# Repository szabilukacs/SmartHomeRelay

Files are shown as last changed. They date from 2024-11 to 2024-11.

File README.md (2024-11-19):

# SmartHome Relay 🌡️🔔

This project is a smart boiler control and monitoring system built on the **Blynk platform**. Using an **ESP32**, this system allows users to:  
- **Remotely control a relay** to activate or deactivate the built-in heating resistance of the boiler.  
- **Monitor the temperature** inside the boiler in real-time.  
- **Automate boiler heating** using thermostat-like behavior based on a set temperature range.  
- **Enable or disable notifications** for temperature changes or system events.

The project combines hardware design, embedded programming, and IoT integration for a seamless smart home experience.

---

## 📜 Table of Contents  

- [✨ Features](#features)  
- [🚀 Getting Started](#getting-started)  
  - [Hardware](#hardware)  
  - [Software](#software)  
- [⚙️ Hardware Design](#Hardware-Design)  
  - [Circuit Diagram](#circuit-diagram)  
  - [PCB 3D View](#pcb-3d-view)  
- [📲 Blynk App Interface](#blynk-app-interface)  
- [🛠️ Code Overview](#code-overview)  
  - [Dependencies](#dependencies)  
  - [Uploading the Code](#uploading-the-code)  
- [PCB Design](#pcb-design)  

## Features ✨

- **Remote Control**: Control the heating resistance via the Blynk mobile app.
- **Real-time Temperature Monitoring**: Display temperature data from the boiler directly in the app.
- **Automated Thermostat Mode**: Set a target temperature range, and the system will automatically control the relay.
- **Notification Toggle**: Enable or disable notifications for system status and alerts.
- **Custom PCB Design**: Compact and efficient PCB for the ESP32 and relay circuit, designed in KiCAD.
- **User-friendly Interface**: Intuitive and easy-to-use Blynk app interface for controlling and monitoring.

---

## Getting Started

### Hardware

- **Microcontroller**: ESP32
- **Temperature Sensor**: DS18B20  
- **Relay Module**: Controls the heating resistance
- **Custom PCB**: Designed to integrate the ESP32, relay, and sensor connections  

### Software

- **Arduino IDE**: Development environment for the ESP32 firmware  
- **Blynk**: Cloud-based platform for IoT app creation  
- **KiCAD**: Used for designing the PCB  

---

## Hardware Design📐

### Circuit Diagram
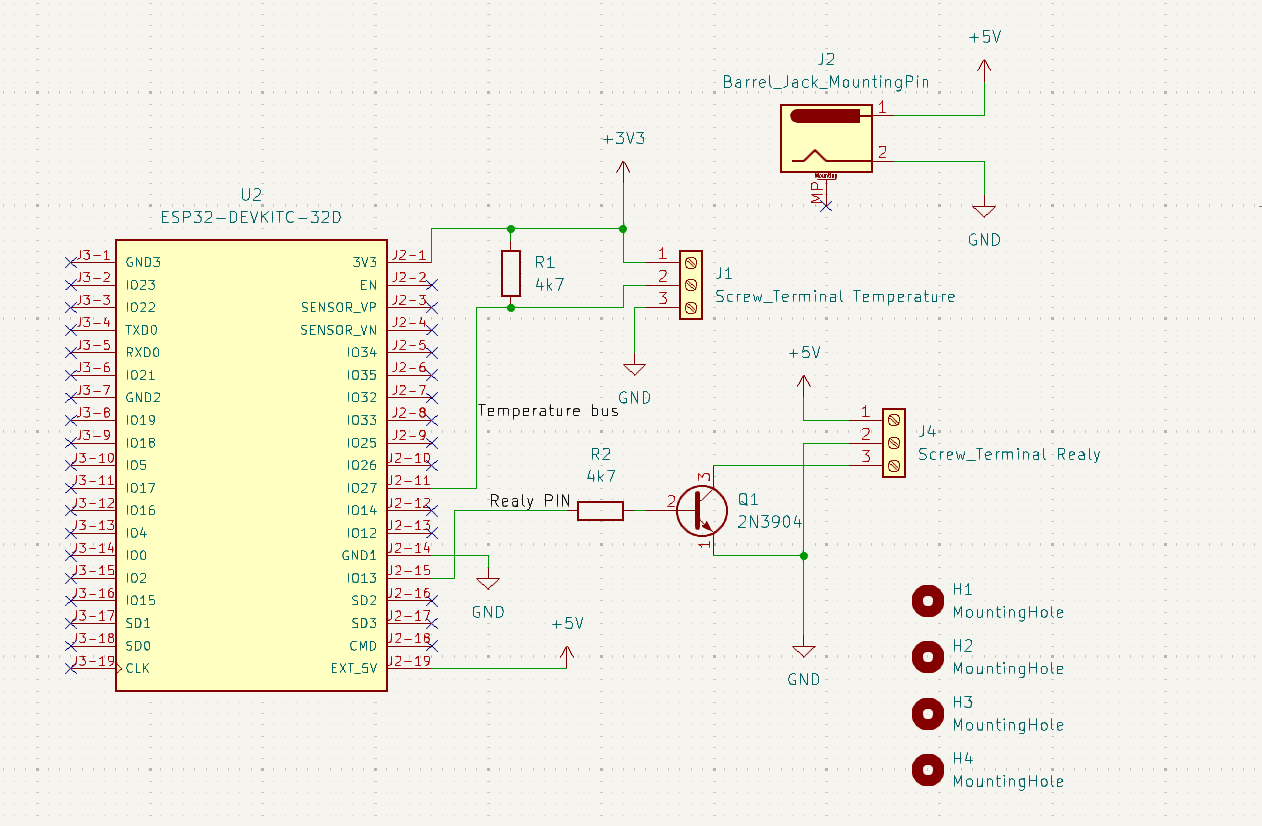
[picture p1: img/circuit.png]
Circuit Diagram


### PCB 3D View
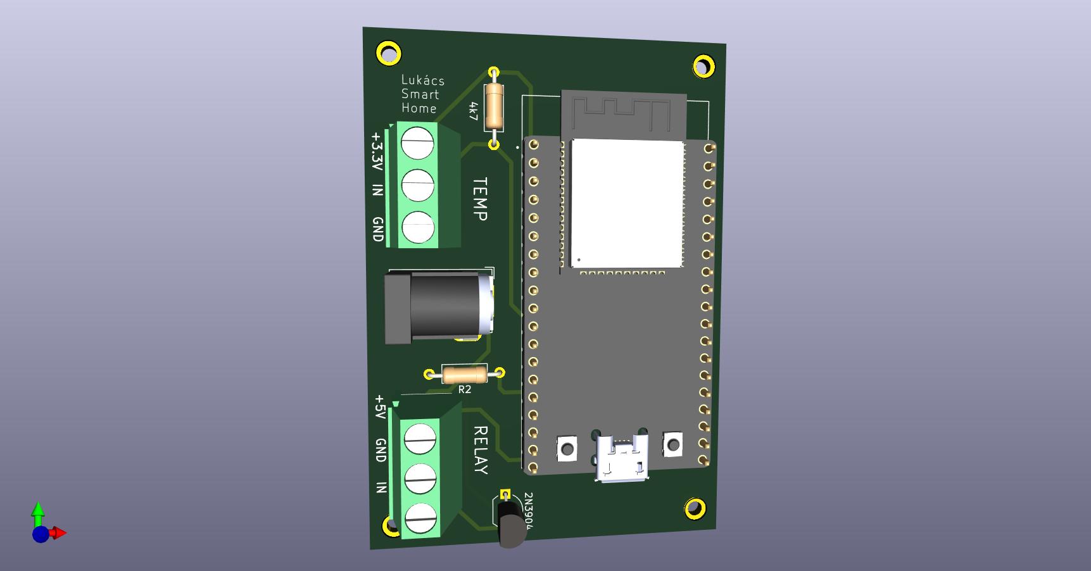
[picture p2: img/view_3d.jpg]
PCB 3D View


---

## Blynk App Interface 📱

The Blynk app provides an intuitive interface for interacting with the SmartHome Relay system:

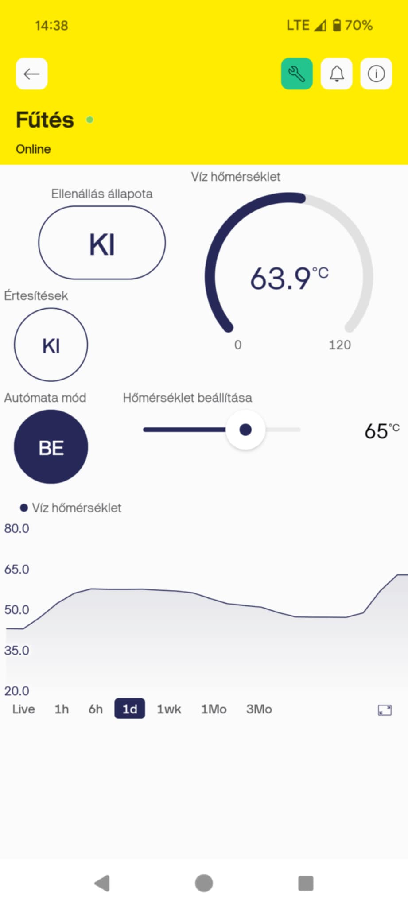
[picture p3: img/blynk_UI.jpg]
Blynk UI


### Features:
- **Relay Control**: Toggle the relay to activate or deactivate the heating resistance.  
- **Temperature Display**: Real-time temperature monitoring from the boiler.  
- **Automation Mode**: Set a target temperature range for thermostat-like operation.  
- **Notifications Toggle**: Enable or disable notifications for system status and alerts.

---

## Code Overview

### Dependencies

Ensure the following libraries are installed in Arduino IDE:
1. **Blynk**  
2. **ESP32 Board Support**  
3. **Temperature Sensor Library**

### Uploading the Code

1. Clone the repository.
2. Open the `.ino` file in Arduino IDE.
3. Configure your WiFi and Blynk credentials in the code.
4. Upload the code to the ESP32 using a USB connection.

---

## PCB Design

- The PCB design was created using **KiCAD**.
- It includes the ESP32, relay, and connectors for the temperature sensor.
- You can [link PCB ordering instructions here] if relevant.

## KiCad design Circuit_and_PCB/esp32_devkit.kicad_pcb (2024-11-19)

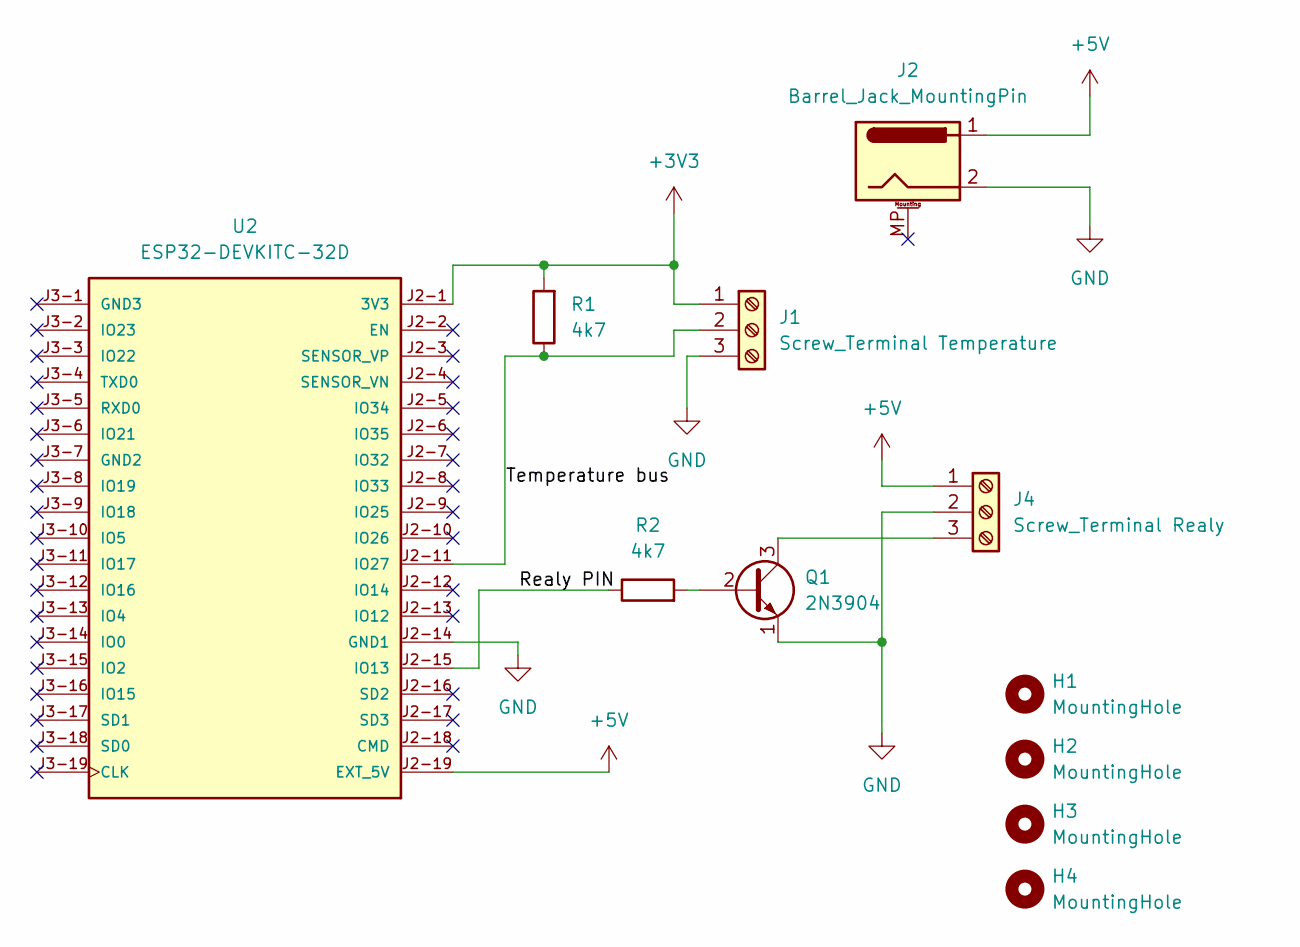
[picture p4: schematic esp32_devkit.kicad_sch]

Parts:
H1, H2, H3, H4: MountingHole; MountingHole_2.2mm_M2_ISO7380_Pad
J1: Screw_Terminal Temperature; TerminalBlock_bornier-3_P5.08mm
J2: Barrel_Jack_MountingPin; BarrelJack_GCT_DCJ200-10-A_Horizontal
J4: Screw_Terminal Realy; TerminalBlock_bornier-3_P5.08mm
Q1: 2N3904; TO-92_Inline_Wide
R1, R2: 4k7; R_Axial_DIN0207_L6.3mm_D2.5mm_P10.16mm_Horizontal
U2: ESP32-DEVKITC-32D; MODULE_ESP32-DEVKITC-32D; PARTREV V4

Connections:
+3V3: J1.1, R1.2, U2.J2-1 (3V3)
+5V: J2.1, J4.1, U2.J2-19 (EXT_5V)
GND: J1.3, J2.2, J4.2, Q1.1 (E), U2.J2-14 (GND1), U2.J3-7 (GND2)
unnamed: J1.2, R1.1, U2.J2-11 (IO27)
unnamed: J4.3, Q1.3 (C)
unnamed: Q1.2 (B), R2.2
unnamed: R2.1, U2.J2-15 (IO13)

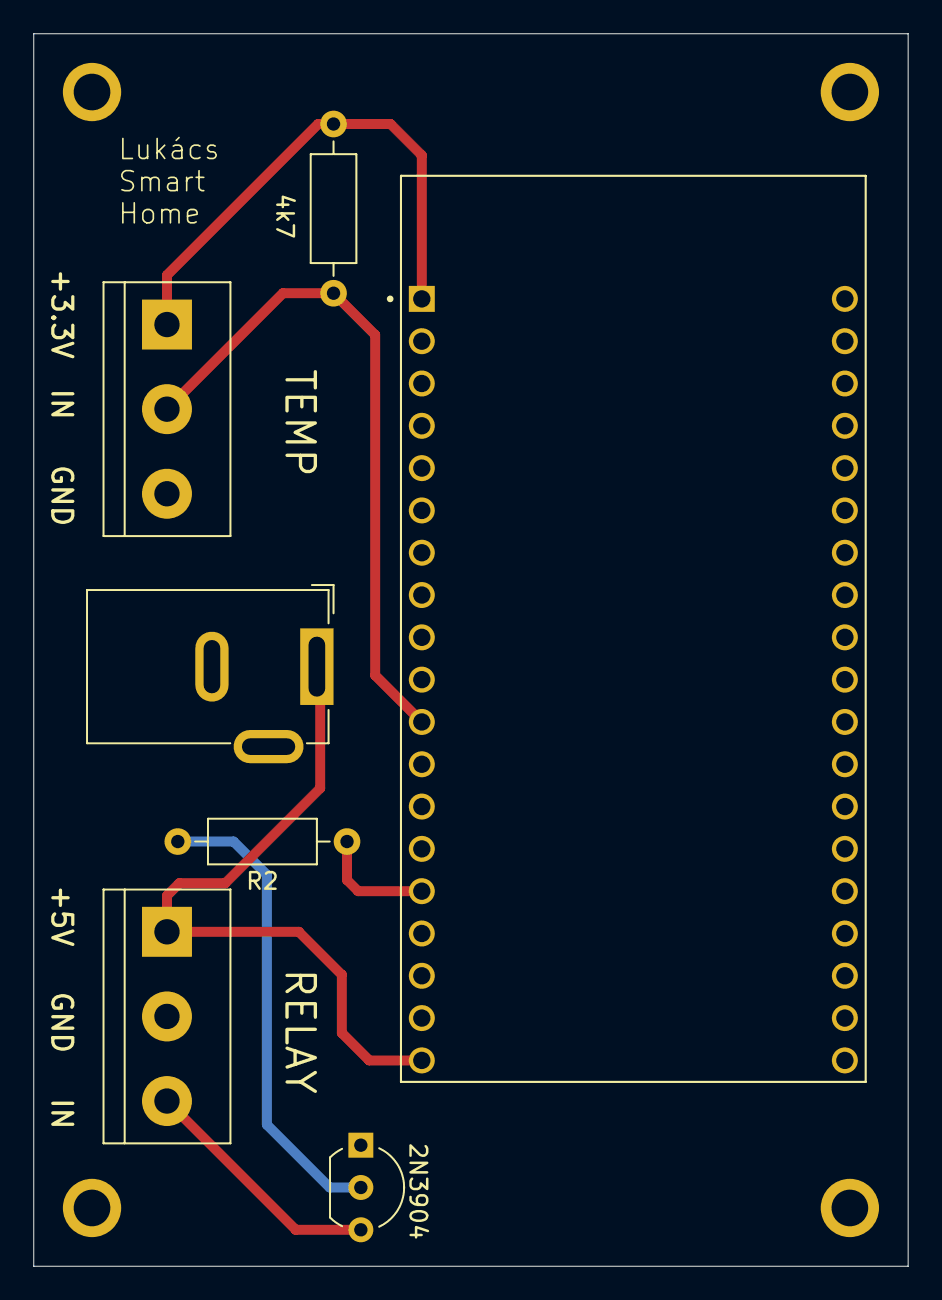
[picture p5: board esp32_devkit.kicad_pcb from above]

Board: 2 copper layers, 52.5 x 74.0 mm, 11 parts (0 on the bottom side), 7 nets.

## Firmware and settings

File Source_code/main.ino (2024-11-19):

#define BLYNK_PRINT Serial

char ssid[] = ""; // your wifi credentials
char pass[] = ""; // your wifi password

// Your Blynk credentials
#define BLYNK_TEMPLATE_ID ""
#define BLYNK_TEMPLATE_NAME ""
char auth[] = "";

#include <WiFi.h>
#include <BlynkSimpleEsp32.h>

#include <OneWire.h>
#include <DallasTemperature.h>

#define ONE_WIRE_BUS 27   // PIN for temperature sensor

#define RELAY_PIN 13      // Relay control PIN

// Onewire init
OneWire oneWire(ONE_WIRE_BUS);
DallasTemperature sensors(&oneWire);

SimpleTimer timer;
DeviceAddress tempDeviceAddress; // Temporary address of the found device

float volatile temperature[2];  // We can store maximum 2 temperature value from 2 sensor
int sensorValue = 0;
int temperature_ref = 0;        // Reference temperature value for termostat function

// Blynk PINs
// Blynk virtual pins connected to the button widget

// Relay switch ON/OFF
#define VPIN_BUTTON V0
// temperature1
#define VPIN_TEMP V1
// Reference temperature control
#define VPIN_TEMP_REF V2
// Notification ON/OFF
#define VPIN_SWITCH_NOTIFY V3
// Automata Mod ON/OFF
#define VPIN_BUTTON_AUTOMATA V4
// (optional) temperature2
#define VPIN_TEMP2 V5
// Safety notification, max temperature of water
#define WATER_HOT_VALUE 70

// Number of temperature devices found
int numberOfDevices;

bool notifications_on = false;

bool auto_mod = false;

void setup() {

  // Debug console
  Serial.begin(115200);
  // Initialize the relay pin as an output
  pinMode(RELAY_PIN, OUTPUT);
  // Start with relay off
  digitalWrite(RELAY_PIN, LOW);
  // Connect to Wi-Fi and Blynk
  Blynk.begin(auth, ssid, pass);

  while (Blynk.connect() == false) {
    // Wait until connected
  }

  // Init the temperature sensors
  init_temperature_sensor();

  timer.setInterval(5000L, sendTemps);    // Read temperature sensor data every 5 minutes

}

// Switch notifications ON/OFF
BLYNK_WRITE(VPIN_SWITCH_NOTIFY) {
  int buttonState = param.asInt(); // Get the value from the widget (0 or 1)

  if (buttonState == 1) {
    notifications_on = true;
  } else {
    notifications_on = false;
  }
}

// Set reference temperature
BLYNK_WRITE(VPIN_TEMP_REF) {
  temperature_ref = param.asInt(); // Get the value from the widget
}

// Switch Automatic mode ON/OFF
BLYNK_WRITE(VPIN_BUTTON_AUTOMATA) {
  int buttonState = param.asInt(); // Get the value from the widget (0 or 1)

  if (buttonState == 1) {
    auto_mod = true;
  } else {
    auto_mod = false;
  }
}

// Switch relay manually
BLYNK_WRITE(VPIN_BUTTON) {
  int buttonState = param.asInt(); // Get the value from the widget (0 or 1)

  if (buttonState == 1) {
    digitalWrite(RELAY_PIN, HIGH);  // Turn on relay
    Serial.println("Relay is ON");
  } else {
    digitalWrite(RELAY_PIN, LOW);   // Turn off relay
    Serial.println("Relay is OFF");
  }
}

void loop() {
  Blynk.run();
  timer.run();
}

void sendTemps()
{
  // Get data from the sensor
  measure_temperature();

  // Filter the -127 value, initializing again
  if ((temperature[0] < -126) && (temperature[0] > -128))
  {
    init_temperature_sensor();
  }
  else
  {
    if (numberOfDevices == 0)
    {
      Serial.println("No device connected!");
      Blynk.logEvent("nincsmeres", String("Hibás mérés, a hőmérsékletmérő nem működik!"));
    }
    if (numberOfDevices == 1)
    {
      Blynk.virtualWrite(VPIN_TEMP, temperature[0]);         // Send temperature to Blynk app virtual pin 1.
    }
    if (numberOfDevices == 2)
    {
      Blynk.virtualWrite(VPIN_TEMP, temperature[0]);         // Send temperature to Blynk app virtual pin 1.
      Blynk.virtualWrite(VPIN_TEMP2, temperature[1]);         // Send temperature to Blynk app virtual pin 2.
    }
  }

  // If Automata Mode is activated turn off the relay if we reached the reference temperature
  if (auto_mod)
  {
    if (temperature[0] >= temperature_ref)
    {
      digitalWrite(RELAY_PIN, LOW);   // Turn off relay
      Blynk.virtualWrite(VPIN_BUTTON, 0);   // switch to 0 virtual pin also
    }
  }

  // If notifications is ON send events for setted references and turn off relay
  if (notifications_on)
  {
    if (temperature[0] >= WATER_HOT_VALUE)
    {
      Blynk.logEvent("tulmelegedes", String("A viz hőmérséklete több mint: ") + WATER_HOT_VALUE + String("A fűtés kikapcsolt!"));
      digitalWrite(RELAY_PIN, LOW);   // Turn off relay
    }

    if (temperature[0] >= temperature_ref)
    {
      Blynk.logEvent("vizjo", String("A viz hőmérséklete elérte a beállított hőfokot!") + temperature[0]);
    }
  }
}

// Get temperature from sensor in Celsius
void measure_temperature()
{
  // Temperatures
  sensors.requestTemperatures(); // Send the command to get temperatures

  if (numberOfDevices == 1)
  {
    temperature[0] = sensors.getTempCByIndex(0);
  }
  if (numberOfDevices == 2)
  {
    temperature[0] = sensors.getTempCByIndex(0);
    temperature[1] = sensors.getTempCByIndex(1);
  }
}

// Initialize temperature sensors
void init_temperature_sensor()
{
  sensors.begin(); // Start up the library
  numberOfDevices = sensors.getDeviceCount(); // Grab a count of devices on the wire

  // locate devices on the bus
  Serial.print("Found ");
  Serial.print(sensors.getDeviceCount(), DEC);
  Serial.println(" devices.");

  // Loop through each device, print out address
  for (int i = 0; i < numberOfDevices; i++)
  {
    // Search the wire for address
    if (sensors.getAddress(tempDeviceAddress, i))
    {
      Serial.print("Found device ");
      Serial.print(i, DEC);
      Serial.print(" with address: ");
      printAddress(tempDeviceAddress);
      Serial.println();
      // set the resolution to 11 bit (Each Dallas/Maxim device is capable of several different resolutions)
      sensors.setResolution(tempDeviceAddress, 11);
    }
    else
    {
      Serial.print("Found ghost device at ");
      Serial.print(i, DEC);
      Serial.print(" but could not detect address. Check power and cabling");
    }
  }
}

// function to print a device address
void printAddress(DeviceAddress deviceAddress) {
  for (uint8_t i = 0; i < 8; i++) {
    if (deviceAddress[i] < 16) Serial.print("0");
    Serial.print(deviceAddress[i], HEX);
  }
}
